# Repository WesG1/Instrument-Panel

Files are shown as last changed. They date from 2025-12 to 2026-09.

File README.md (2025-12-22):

# Instrument Panel
65 Mustang Modern Insturment Panel

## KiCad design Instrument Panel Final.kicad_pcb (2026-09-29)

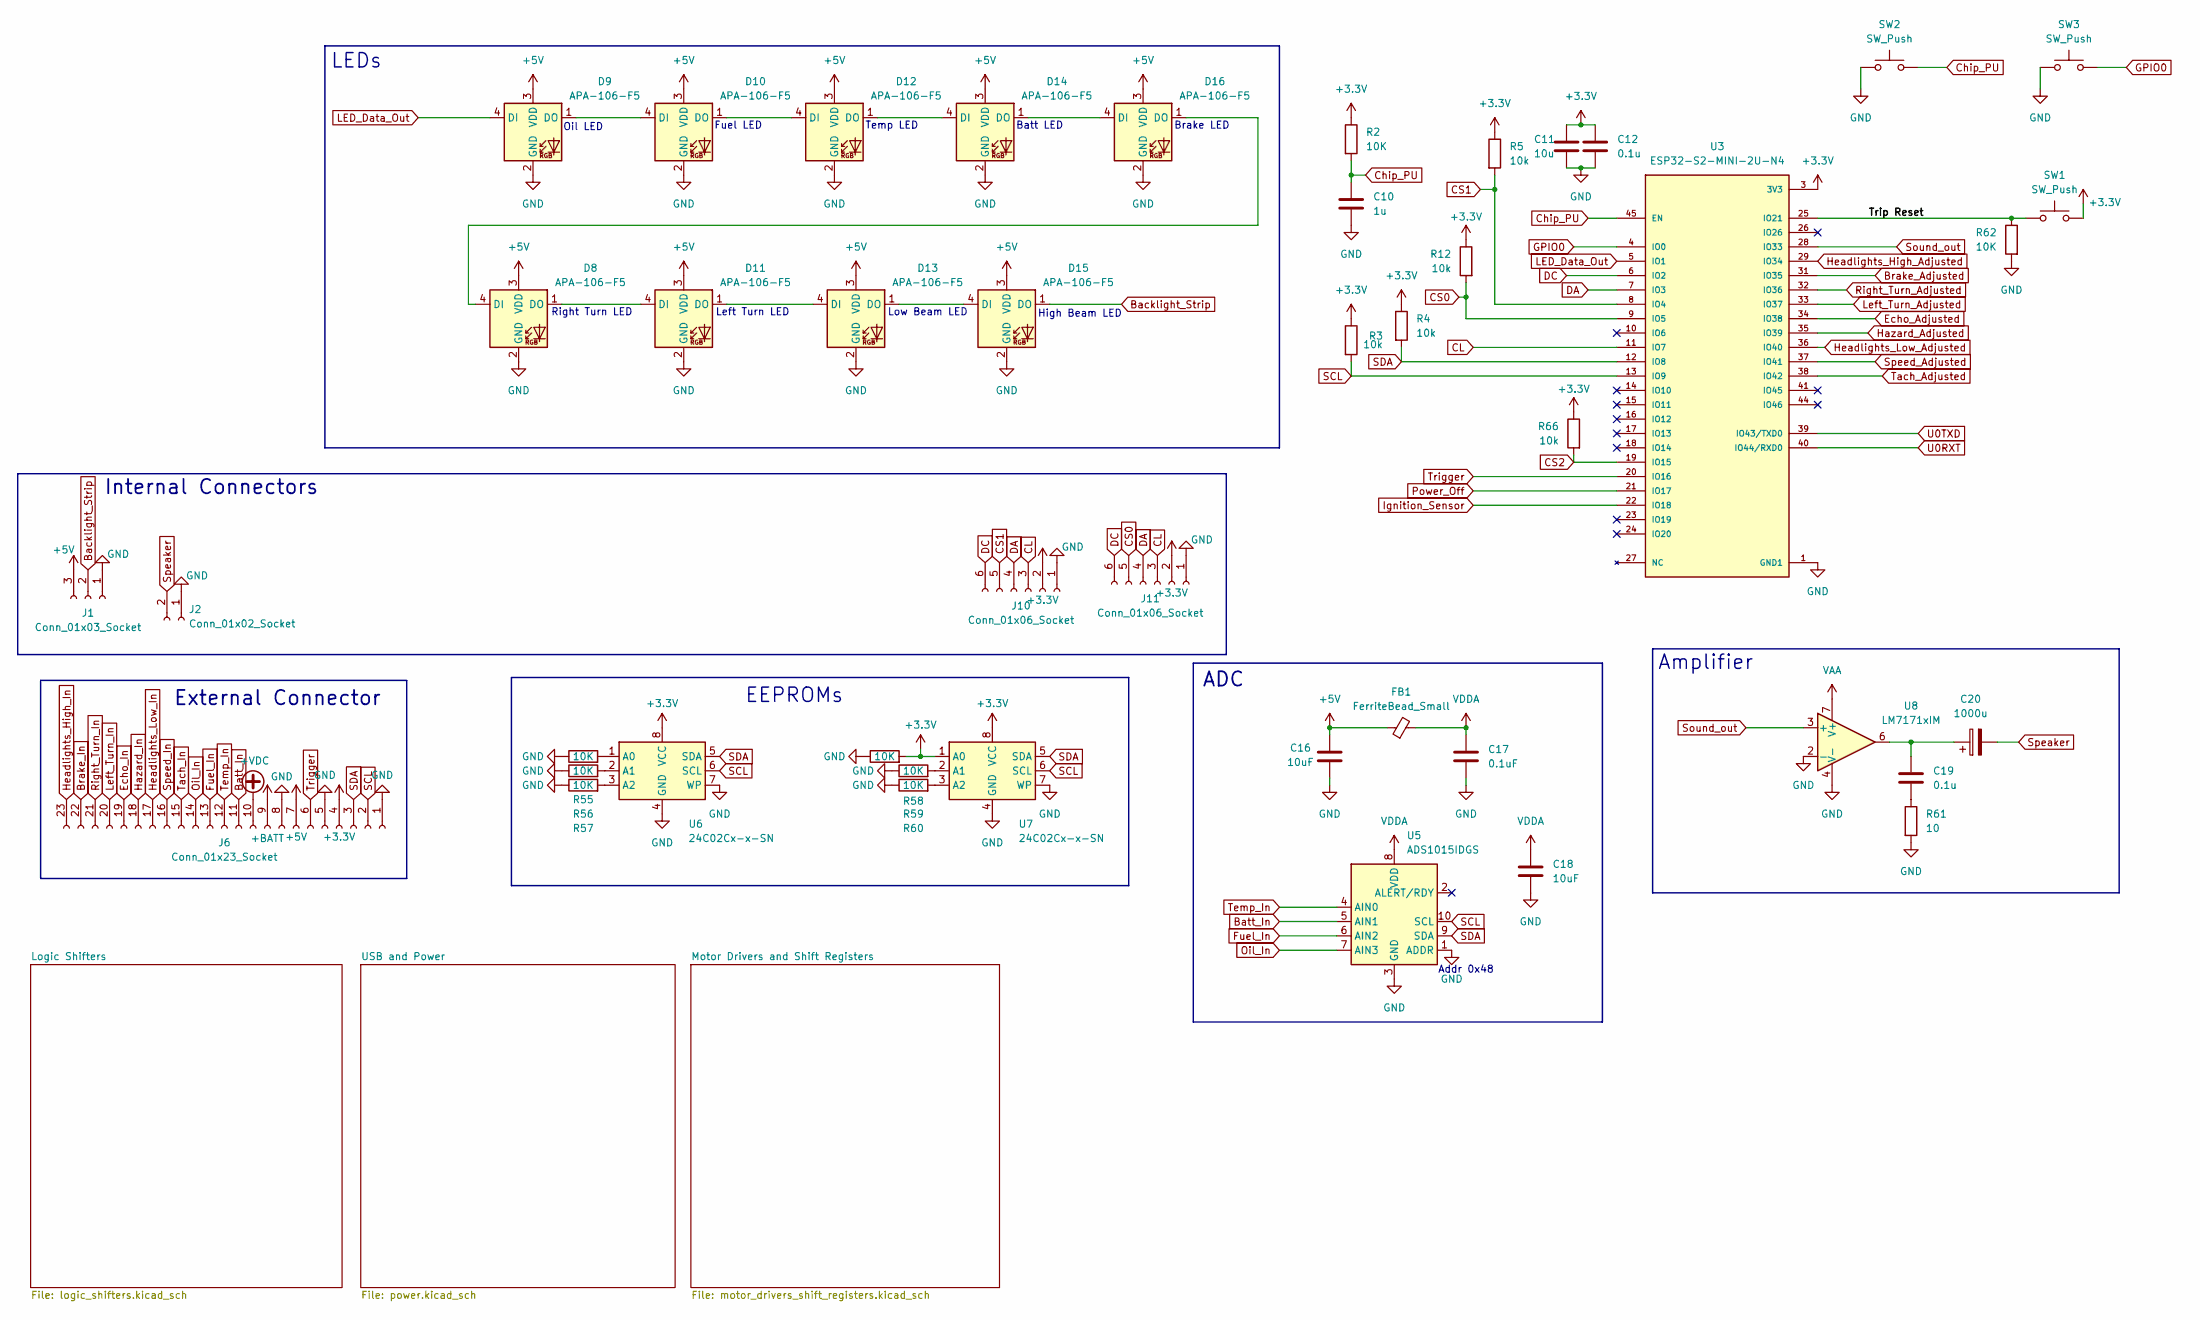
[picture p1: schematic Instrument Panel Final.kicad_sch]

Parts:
C10: 1u; C_Disc_D3.0mm_W1.6mm_P2.50mm
C11: 10u; C_Disc_D3.0mm_W1.6mm_P2.50mm
C12, C19: 0.1u; C_Disc_D3.0mm_W1.6mm_P2.50mm
C16, C18: 10uF; C_Disc_D3.0mm_W1.6mm_P2.50mm
C17: 0.1uF; C_Disc_D3.0mm_W1.6mm_P2.50mm
C20: 1000u; CP_Radial_D5.0mm_P2.50mm
D8, D9, D10, D11, D12, D13, D14, D15, D16: APA-106-F5; LED_D5.0mm-4_RGB
FB1: FerriteBead_Small; L_Axial_L5.0mm_D3.6mm_P10.00mm_Horizontal_Murata_BL01RN1A2A2
J1: Conn_01x03_Socket; Hirose_DF13-03P-1.25DSA_1x03_P1.25mm_Vertical
J2: Conn_01x02_Socket; Hirose_DF13-02P-1.25DSA_1x02_P1.25mm_Vertical
J6: Conn_01x23_Socket; Molex_SL_171971-0023_1x23_P2.54mm_Vertical
J10, J11: Conn_01x06_Socket; Hirose_DF13-06P-1.25DSA_1x06_P1.25mm_Vertical
R2, R55, R56, R57, R58, R59, R60, R62: 10K; R_Axial_DIN0207_L6.3mm_D2.5mm_P10.16mm_Horizontal
R3, R4, R5, R12, R66: 10k; R_Axial_DIN0207_L6.3mm_D2.5mm_P10.16mm_Horizontal
R61: 10; R_Axial_DIN0207_L6.3mm_D2.5mm_P10.16mm_Horizontal
SW1, SW2, SW3: SW_Push; SW_PUSH_6mm_H8mm
U3: ESP32-S2-MINI-2U-N4; XCVR_ESP32-S2-MINI-2U-N4; PARTREV v0.5
U5: ADS1015IDGS; TSSOP-10_3x3mm_P0.5mm
U6, U7: 24C02Cx-x-SN; DIP-8_W7.62mm
U8: LM7171xIM; DIP-8_W7.62mm

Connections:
+3.3V: C11.1, C12.1, J6.4, J10.2, J11.2, R2.1, R3.1, R4.1, R5.1, R12.1, R58.2, R66.1, SW1.1, U3.3 (3V3), U6.8 (VCC), U7.1 (A0), U7.8 (VCC); also elsewhere on the board
+5V: C16.1, D8.3 (VDD), D9.3 (VDD), D10.3 (VDD), D11.3 (VDD), D12.3 (VDD), D13.3 (VDD), D14.3 (VDD), D15.3 (VDD), D16.3 (VDD), FB1.1, J1.3, J6.7; also elsewhere on the board
+BATT: J6.9; also elsewhere on the board
+VDC: J6.10; also elsewhere on the board
Backlight_Strip: D15.1 (DO), J1.2
Batt_In: J6.11, U5.5 (AIN1)
Brake_Adjusted: U3.31 (IO35); also elsewhere on the board
Brake_In: J6.22; also elsewhere on the board
CL: J10.3, J11.3, U3.11 (IO7); also elsewhere on the board
CS0: J11.5, R12.2, U3.9 (IO5)
CS1: J10.5, R5.2, U3.8 (IO4)
Chip_PU: C10.1, R2.2, SW2.2, U3.45 (EN); also elsewhere on the board
DA: J10.4, J11.4, U3.7 (IO3); also elsewhere on the board
DC: J10.6, J11.6, U3.6 (IO2)
Echo_Adjusted: U3.34 (IO38); also elsewhere on the board
Echo_In: J6.19; also elsewhere on the board
Fuel_In: J6.13, U5.6 (AIN2)
GND: C10.2, C11.2, C12.2, C16.2, C17.2, C18.2, D8.2 (GND), D9.2 (GND), D10.2 (GND), D11.2 (GND), D12.2 (GND), D13.2 (GND), D14.2 (GND), D15.2 (GND), D16.2 (GND), J1.1, J2.1, J6.1, J6.5, J6.8, J10.1, J11.1, R55.1, R56.1, R57.1, R58.1, R59.1, R60.1, R61.2, R62.2, SW2.1, SW3.1, U3.1 (GND1), U3.2 (GND1__1), U3.30 (GND1__2), U3.42 (GND1__3), U3.43 (GND1__4), U3.46 (GND1__5), U3.47 (GND1__6), U3.48 (GND1__7), U3.49 (GND1__8), U3.50 (GND1__9), U3.51 (GND1__10), U3.52 (GND1__11), U3.53 (GND1__12), U3.54 (GND1__13), U3.55 (GND1__14), U3.56 (GND2), U3.57 (GND2__1), U3.58 (GND2__2), U3.59 (GND2__3), U3.60 (GND2__4), U3.61_1 (GND2__5), U3.61_2 (GND2__6), U3.61_3 (GND2__7), U3.61_4 (GND2__8), U3.61_5 (GND2__9), U3.61_6 (GND2__10), U3.61_7 (GND2__11), U3.61_8 (GND2__12), U3.61_9 (GND2__13), U3.62 (GND2__14), U3.63 (GND3), U3.64 (GND3__1), U3.65 (GND3__2), U5.1 (ADDR), U5.3 (GND), U6.4 (GND), U6.7 (WP), U7.4 (GND), U7.7 (WP), U8.2 (-), U8.4 (V-); also elsewhere on the board
GPIO0: SW3.2, U3.4 (IO0); also elsewhere on the board
Hazard_Adjusted: U3.35 (IO39); also elsewhere on the board
Hazard_In: J6.18; also elsewhere on the board
Headlights_High_Adjusted: U3.29 (IO34); also elsewhere on the board
Headlights_High_In: J6.23; also elsewhere on the board
Headlights_Low_Adjusted: U3.36 (IO40); also elsewhere on the board
Headlights_Low_In: J6.17; also elsewhere on the board
Ignition_Sensor: U3.22 (IO18); also elsewhere on the board
LED_Data_Out: D9.4 (DI), U3.5 (IO1)
Left_Turn_Adjusted: U3.33 (IO37); also elsewhere on the board
Left_Turn_In: J6.20; also elsewhere on the board
unnamed: C19.1, C20.1, U8.6
unnamed: C19.2, R61.1
unnamed: D9.1 (DO), D10.4 (DI)
unnamed: D10.1 (DO), D12.4 (DI)
unnamed: D8.1 (DO), D11.4 (DI)
unnamed: D11.1 (DO), D13.4 (DI)
unnamed: D12.1 (DO), D14.4 (DI)
unnamed: D13.1 (DO), D15.4 (DI)
unnamed: D14.1 (DO), D16.4 (DI)
unnamed: D8.4 (DI), D16.1 (DO)
unnamed: R66.2, U3.19 (IO15)
unnamed: R55.2, U6.1 (A0)
unnamed: R56.2, U6.2 (A1)
unnamed: R57.2, U6.3 (A2)
unnamed: R59.2, U7.2 (A1)
unnamed: R60.2, U7.3 (A2)
Oil_In: J6.14, U5.7 (AIN3)
Power_Off: U3.21 (IO17); also elsewhere on the board
Right_Turn_Adjusted: U3.32 (IO36); also elsewhere on the board
Right_Turn_In: J6.21; also elsewhere on the board
SCL: J6.2, R3.2, U3.13 (IO9), U5.10 (SCL), U6.6 (SCL), U7.6 (SCL)
SDA: J6.3, R4.2, U3.12 (IO8), U5.9 (SDA), U6.5 (SDA), U7.5 (SDA)
Sound_out: U3.28 (IO33), U8.3 (+)
Speaker: C20.2, J2.2
Speed_Adjusted: U3.37 (IO41); also elsewhere on the board
Speed_In: J6.16; also elsewhere on the board
Tach_Adjusted: U3.38 (IO42); also elsewhere on the board
Tach_In: J6.15; also elsewhere on the board
Temp_In: J6.12, U5.4 (AIN0)
Trigger: J6.6, U3.20 (IO16)
Trip_Reset: R62.1, SW1.2, U3.25 (IO21)
U0RXT: U3.40 (IO44/RXD0); also elsewhere on the board
U0TXD: U3.39 (IO43/TXD0); also elsewhere on the board
VAA: U8.7 (V+); also elsewhere on the board
VDDA: C17.1, C18.1, FB1.2, U5.8 (VDD)

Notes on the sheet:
Brake LED
Batt LED
High Beam LED
Addr 0x48
LEDs
Fuel LED
Left Turn LED
ADC
Amplifier
Temp LED
EEPROMs
Oil LED
Low Beam LED
Right Turn LED
External Connector
Internal Connectors

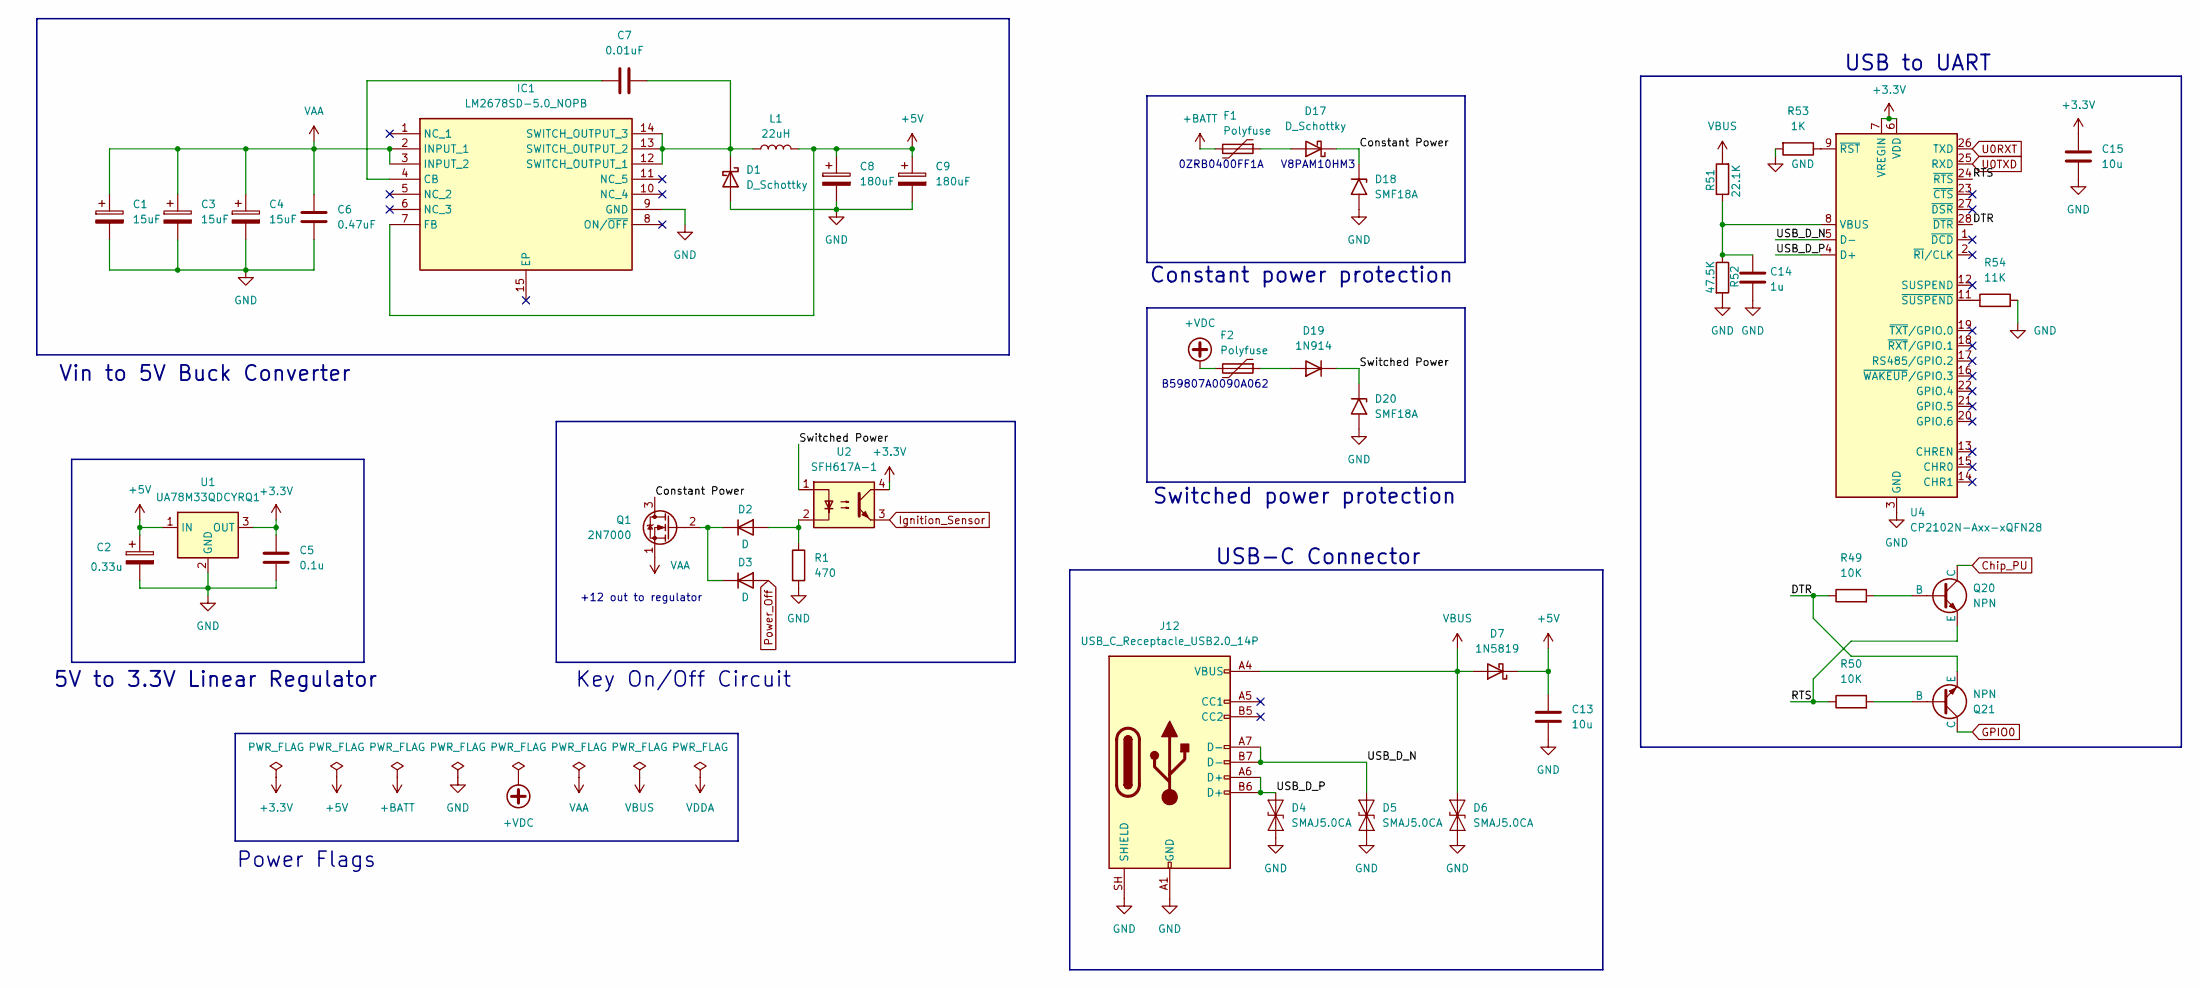
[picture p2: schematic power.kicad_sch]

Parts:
C1, C3, C4: 15uF; CP_Radial_D5.0mm_P2.50mm
C2: 0.33u; CP_Radial_D5.0mm_P2.50mm
C5: 0.1u; C_Disc_D3.0mm_W1.6mm_P2.50mm
C6: 0.47uF; C_Disc_D3.0mm_W1.6mm_P2.50mm
C7: 0.01uF; C_Disc_D3.0mm_W1.6mm_P2.50mm
C8, C9: 180uF; CP_Radial_D5.0mm_P2.50mm
C13, C15: 10u; C_Disc_D3.0mm_W1.6mm_P2.50mm
C14: 1u; C_Disc_D3.0mm_W1.6mm_P2.50mm
D1: D_Schottky; D_A-405_P7.62mm_Horizontal
D2, D3: D; D_A-405_P7.62mm_Horizontal
D4, D5, D6: SMAJ5.0CA; D_SMA
D7: 1N5819; D_DO-41_SOD81_P10.16mm_Horizontal
D17: D_Schottky; Vishay_SMPA
D18, D20: SMF18A; D_SMF
D19: 1N914; D_DO-35_SOD27_P7.62mm_Horizontal
F1: Polyfuse; Fuse_BelFuse_0ZRE0005FF_L8.3mm_W3.8mm
F2: Polyfuse; Fuse_1210_3225Metric
IC1: LM2678SD-5.0_NOPB; VSON-14-1EP_3x4.45mm_P0.65mm_EP1.6x4.2mm; Manufacturer_Part_Number LM2678SD-5.0/NOPB; Mouser Part Number 926-LM2678SD50NOPB
J12: USB_C_Receptacle_USB2.0_14P; USB_C_Receptacle_GCT_USB4085
L1: 22uH; L_Radial_D9.5mm_P5.00mm_Fastron_07HVP
Q1: 2N7000; TO-92_Inline
Q20, Q21: NPN; TO-92_Inline
R1: 470; R_Axial_DIN0207_L6.3mm_D2.5mm_P10.16mm_Horizontal
R49, R50: 10K; R_Axial_DIN0207_L6.3mm_D2.5mm_P10.16mm_Horizontal
R51: 22.1K; R_Axial_DIN0207_L6.3mm_D2.5mm_P10.16mm_Horizontal
R52: 47.5K; R_Axial_DIN0207_L6.3mm_D2.5mm_P10.16mm_Horizontal
R53: 1K; R_Axial_DIN0207_L6.3mm_D2.5mm_P10.16mm_Horizontal
R54: 11K; R_Axial_DIN0207_L6.3mm_D2.5mm_P10.16mm_Horizontal
U1: UA78M33QDCYRQ1; SOT-223-3_TabPin2
U2: SFH617A-1; DIP-4_W7.62mm
U4: CP2102N-Axx-xQFN28; QFN-28-1EP_5x5mm_P0.5mm_EP3.35x3.35mm

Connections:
+3.3V: C5.1, C15.1, U1.3 (OUT), U2.4, U4.6 (VDD), U4.7 (VREGIN); also elsewhere on the board
+5V: C2.1, C8.1, C9.1, C13.1, D7.1 (K), IC1.7 (FB), L1.2, U1.1 (IN); also elsewhere on the board
+BATT: F1.2; also elsewhere on the board
+VDC: F2.2; also elsewhere on the board
/Power/Constant Power: D17.1 (K), D18.1 (A1), Q1.3 (D)
/Power/Switched Power: D19.1 (K), D20.1 (A1), U2.1
/USB/DTR: Q21.3 (E), R49.1, U4.28 (~DTR)
/USB/RTS: Q20.3 (E), R50.1, U4.24 (~RTS)
/USB/USB_D_N: D5.2 (A2), J12.A7 (D-), J12.B7 (D-), U4.5 (D-)
/USB/USB_D_P: D4.2 (A2), J12.A6 (D+), J12.B6 (D+), U4.4 (D+)
Chip_PU: Q20.1 (C); also elsewhere on the board
GND: C1.2, C2.2, C3.2, C4.2, C5.2, C6.2, C8.2, C9.2, C13.2, C14.2, C15.2, D1.2 (A), D4.1 (A1), D5.1 (A1), D6.1 (A1), D18.2 (A2), D20.2 (A2), IC1.9 (GND), J12.A1 (GND), J12.A12 (GND), J12.B1 (GND), J12.B12 (GND), J12.SH (SHIELD), R1.2, R52.2, R53.2, R54.2, U1.2 (GND), U4.3 (GND), U4.29 (GND); also elsewhere on the board
GPIO0: Q21.1 (C); also elsewhere on the board
Ignition_Sensor: U2.3; also elsewhere on the board
unnamed: C7.2, D1.1 (K), IC1.12 (SWITCH_OUTPUT_1), IC1.13 (SWITCH_OUTPUT_2), IC1.14 (SWITCH_OUTPUT_3), L1.1
unnamed: D2.2 (A), R1.1, U2.2
unnamed: D2.1 (K), D3.1 (K), Q1.2 (G)
unnamed: D17.2 (A), F1.1
unnamed: D19.2 (A), F2.1
unnamed: C7.1, IC1.4 (CB)
unnamed: Q20.2 (B), R49.2
unnamed: Q21.2 (B), R50.2
unnamed: C14.1, R51.1, R52.1, U4.8 (VBUS)
unnamed: R53.1, U4.9 (~RST)
unnamed: R54.1, U4.11 (~SUSPEND)
Power_Off: D3.2 (A); also elsewhere on the board
U0RXT: U4.26 (TXD); also elsewhere on the board
U0TXD: U4.25 (RXD); also elsewhere on the board
VAA: C1.1, C3.1, C4.1, C6.1, IC1.2 (INPUT_1), IC1.3 (INPUT_2), Q1.1 (S); also elsewhere on the board
VBUS: D6.2 (A2), D7.2 (A), J12.A4 (VBUS), J12.A9 (VBUS), J12.B4 (VBUS), J12.B9 (VBUS), R51.2

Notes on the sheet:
USB to UART
V8PAM10HM3
0ZRB0400FF1A
Constant power protection
Key On/Off Circuit
+12 out to regulator
Vin to 5V Buck Converter
B59807A0090A062
Power Flags
USB-C Connector
5V to 3.3V Linear Regulator
Switched power protection

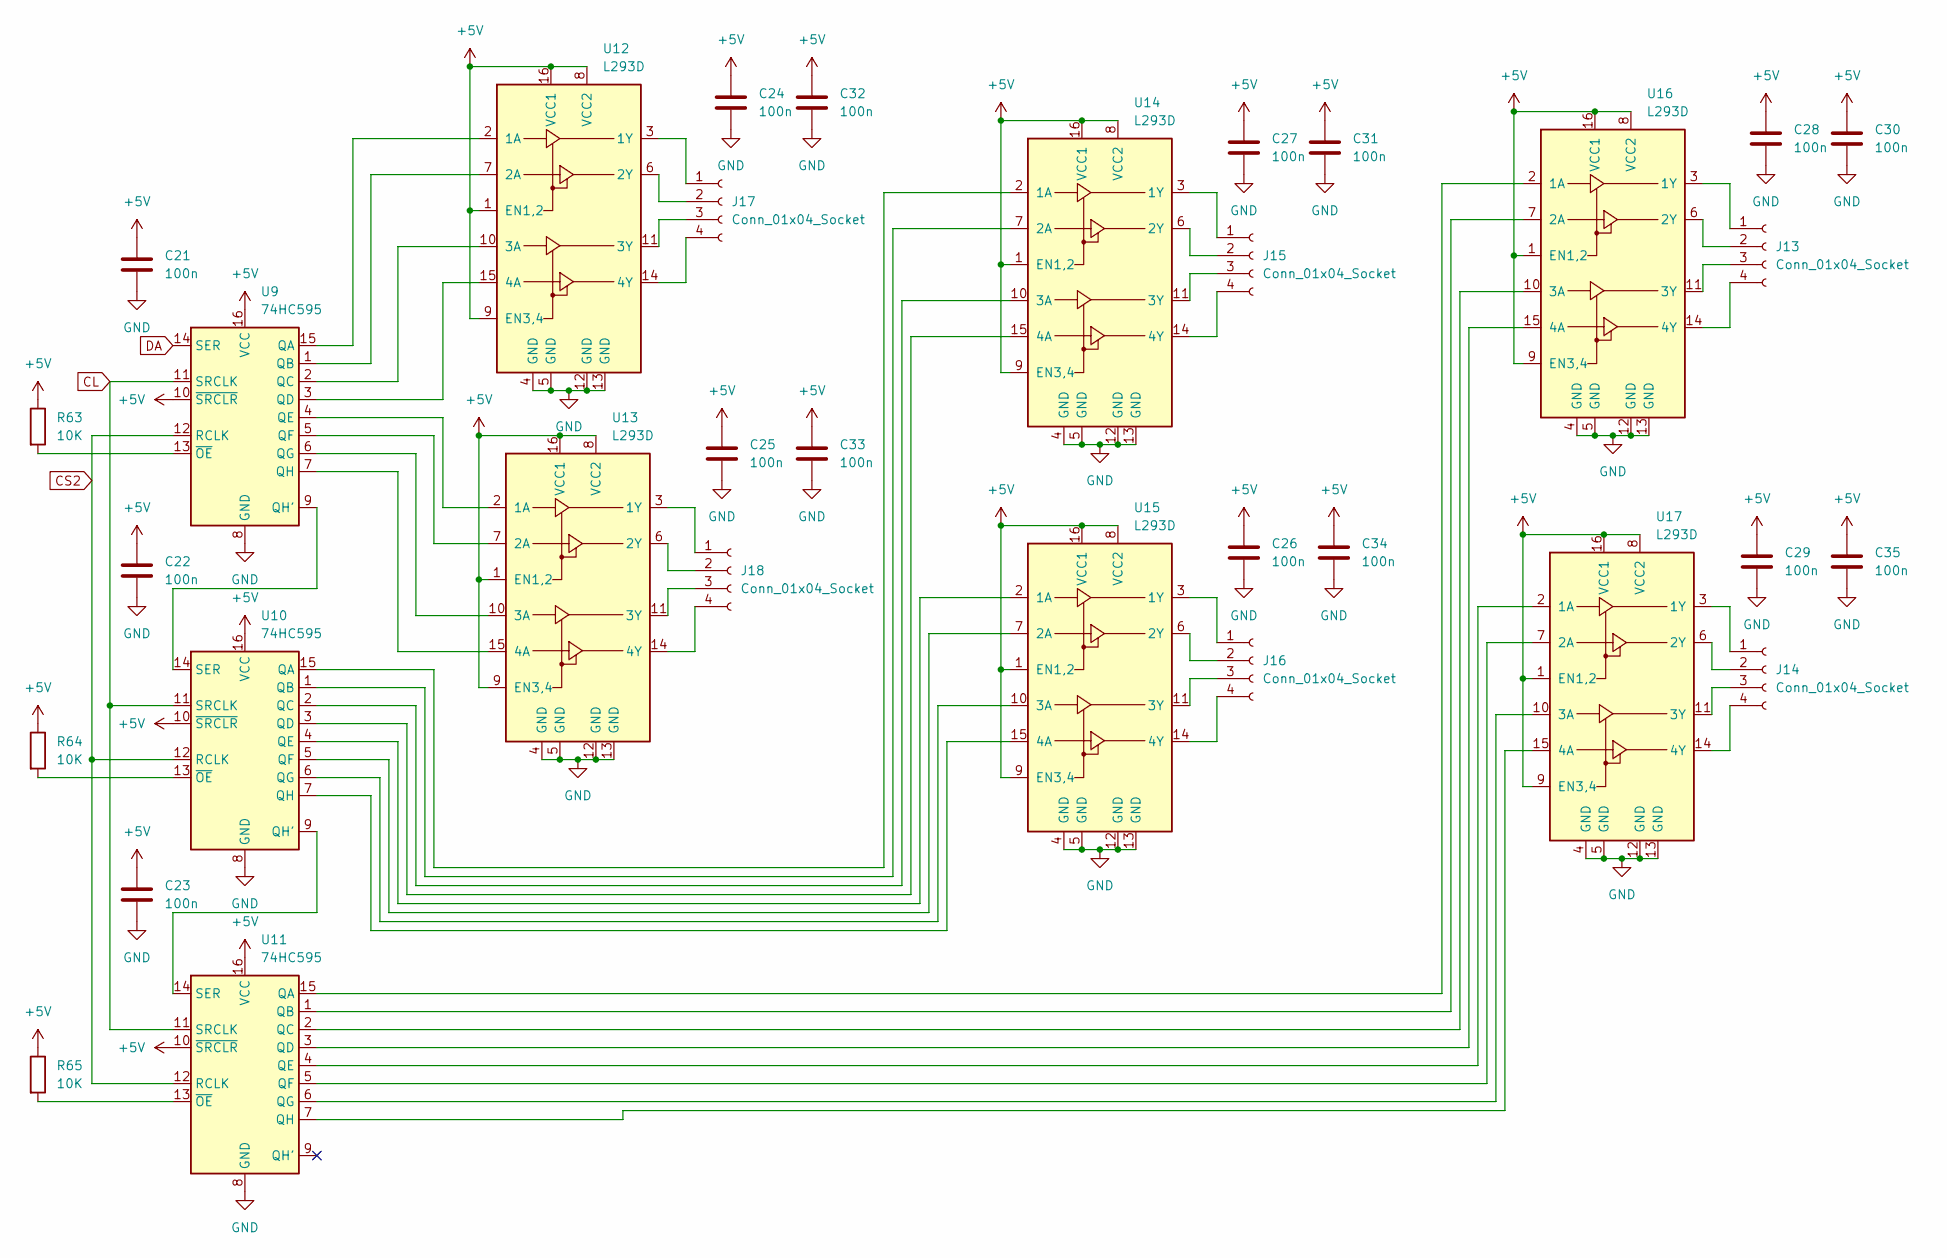
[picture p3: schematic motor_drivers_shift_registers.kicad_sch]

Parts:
C21, C22, C23, C24, C25, C26, C27, C28, C29, C30, C31, C32, C33, C34, C35: 100n; C_Disc_D3.0mm_W1.6mm_P2.50mm
J13, J14, J15, J16, J17, J18: Conn_01x04_Socket; Hirose_DF13-04P-1.25DSA_1x04_P1.25mm_Vertical
R63, R64, R65: 10K; R_Axial_DIN0207_L6.3mm_D2.5mm_P10.16mm_Horizontal
U9, U10, U11: 74HC595; DIP-16_W7.62mm
U12, U13, U14, U15, U16, U17: L293D; DIP-16_W7.62mm

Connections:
+5V: C21.1, C22.1, C23.1, C24.1, C25.1, C26.1, C27.1, C28.1, C29.1, C30.1, C31.1, C32.1, C33.1, C34.1, C35.1, R63.1, R64.1, R65.1, U9.10 (~SRCLR), U9.16 (VCC), U10.10 (~SRCLR), U10.16 (VCC), U11.10 (~SRCLR), U11.16 (VCC), U12.1 (EN1,2), U12.8 (VCC2), U12.9 (EN3,4), U12.16 (VCC1), U13.1 (EN1,2), U13.8 (VCC2), U13.9 (EN3,4), U13.16 (VCC1), U14.1 (EN1,2), U14.8 (VCC2), U14.9 (EN3,4), U14.16 (VCC1), U15.1 (EN1,2), U15.8 (VCC2), U15.9 (EN3,4), U15.16 (VCC1), U16.1 (EN1,2), U16.8 (VCC2), U16.9 (EN3,4), U16.16 (VCC1), U17.1 (EN1,2), U17.8 (VCC2), U17.9 (EN3,4), U17.16 (VCC1); also elsewhere on the board
CL: U9.11 (SRCLK), U10.11 (SRCLK), U11.11 (SRCLK); also elsewhere on the board
CS2: U9.12 (RCLK), U10.12 (RCLK), U11.12 (RCLK)
DA: U9.14 (SER); also elsewhere on the board
GND: C21.2, C22.2, C23.2, C24.2, C25.2, C26.2, C27.2, C28.2, C29.2, C30.2, C31.2, C32.2, C33.2, C34.2, C35.2, U9.8 (GND), U10.8 (GND), U11.8 (GND), U12.4 (GND), U12.5 (GND), U12.12 (GND), U12.13 (GND), U13.4 (GND), U13.5 (GND), U13.12 (GND), U13.13 (GND), U14.4 (GND), U14.5 (GND), U14.12 (GND), U14.13 (GND), U15.4 (GND), U15.5 (GND), U15.12 (GND), U15.13 (GND), U16.4 (GND), U16.5 (GND), U16.12 (GND), U16.13 (GND), U17.4 (GND), U17.5 (GND), U17.12 (GND), U17.13 (GND); also elsewhere on the board
unnamed: J13.1, U16.3 (1Y)
unnamed: J13.2, U16.6 (2Y)
unnamed: J13.3, U16.11 (3Y)
unnamed: J13.4, U16.14 (4Y)
unnamed: J14.1, U17.3 (1Y)
unnamed: J14.2, U17.6 (2Y)
unnamed: J14.3, U17.11 (3Y)
unnamed: J14.4, U17.14 (4Y)
unnamed: J15.1, U14.3 (1Y)
unnamed: J15.2, U14.6 (2Y)
unnamed: J15.3, U14.11 (3Y)
unnamed: J15.4, U14.14 (4Y)
unnamed: J16.1, U15.3 (1Y)
unnamed: J16.2, U15.6 (2Y)
unnamed: J16.3, U15.11 (3Y)
unnamed: J16.4, U15.14 (4Y)
unnamed: J17.1, U12.3 (1Y)
unnamed: J17.2, U12.6 (2Y)
unnamed: J17.3, U12.11 (3Y)
unnamed: J17.4, U12.14 (4Y)
unnamed: J18.1, U13.3 (1Y)
unnamed: J18.2, U13.6 (2Y)
unnamed: J18.3, U13.11 (3Y)
unnamed: J18.4, U13.14 (4Y)
unnamed: R63.2, U9.13 (~OE)
unnamed: U10.15 (QA), U14.2 (1A)
unnamed: U10.1 (QB), U14.7 (2A)
unnamed: U10.2 (QC), U14.10 (3A)
unnamed: U10.3 (QD), U14.15 (4A)
unnamed: U10.4 (QE), U15.2 (1A)
unnamed: U10.5 (QF), U15.7 (2A)
unnamed: U10.6 (QG), U15.10 (3A)
unnamed: U10.9 (QH'), U11.14 (SER)
unnamed: U10.7 (QH), U15.15 (4A)
unnamed: U9.9 (QH'), U10.14 (SER)
unnamed: R64.2, U10.13 (~OE)
unnamed: U11.15 (QA), U16.2 (1A)
unnamed: U11.1 (QB), U16.7 (2A)
unnamed: U11.2 (QC), U16.10 (3A)
unnamed: U11.3 (QD), U16.15 (4A)
unnamed: U11.4 (QE), U17.2 (1A)
unnamed: U11.5 (QF), U17.7 (2A)
unnamed: U11.6 (QG), U17.10 (3A)
unnamed: U11.7 (QH), U17.15 (4A)
unnamed: R65.2, U11.13 (~OE)
unnamed: U9.15 (QA), U12.2 (1A)
unnamed: U9.1 (QB), U12.7 (2A)
unnamed: U9.2 (QC), U12.10 (3A)
unnamed: U9.3 (QD), U12.15 (4A)
unnamed: U9.4 (QE), U13.2 (1A)
unnamed: U9.5 (QF), U13.7 (2A)
unnamed: U9.6 (QG), U13.10 (3A)
unnamed: U9.7 (QH), U13.15 (4A)

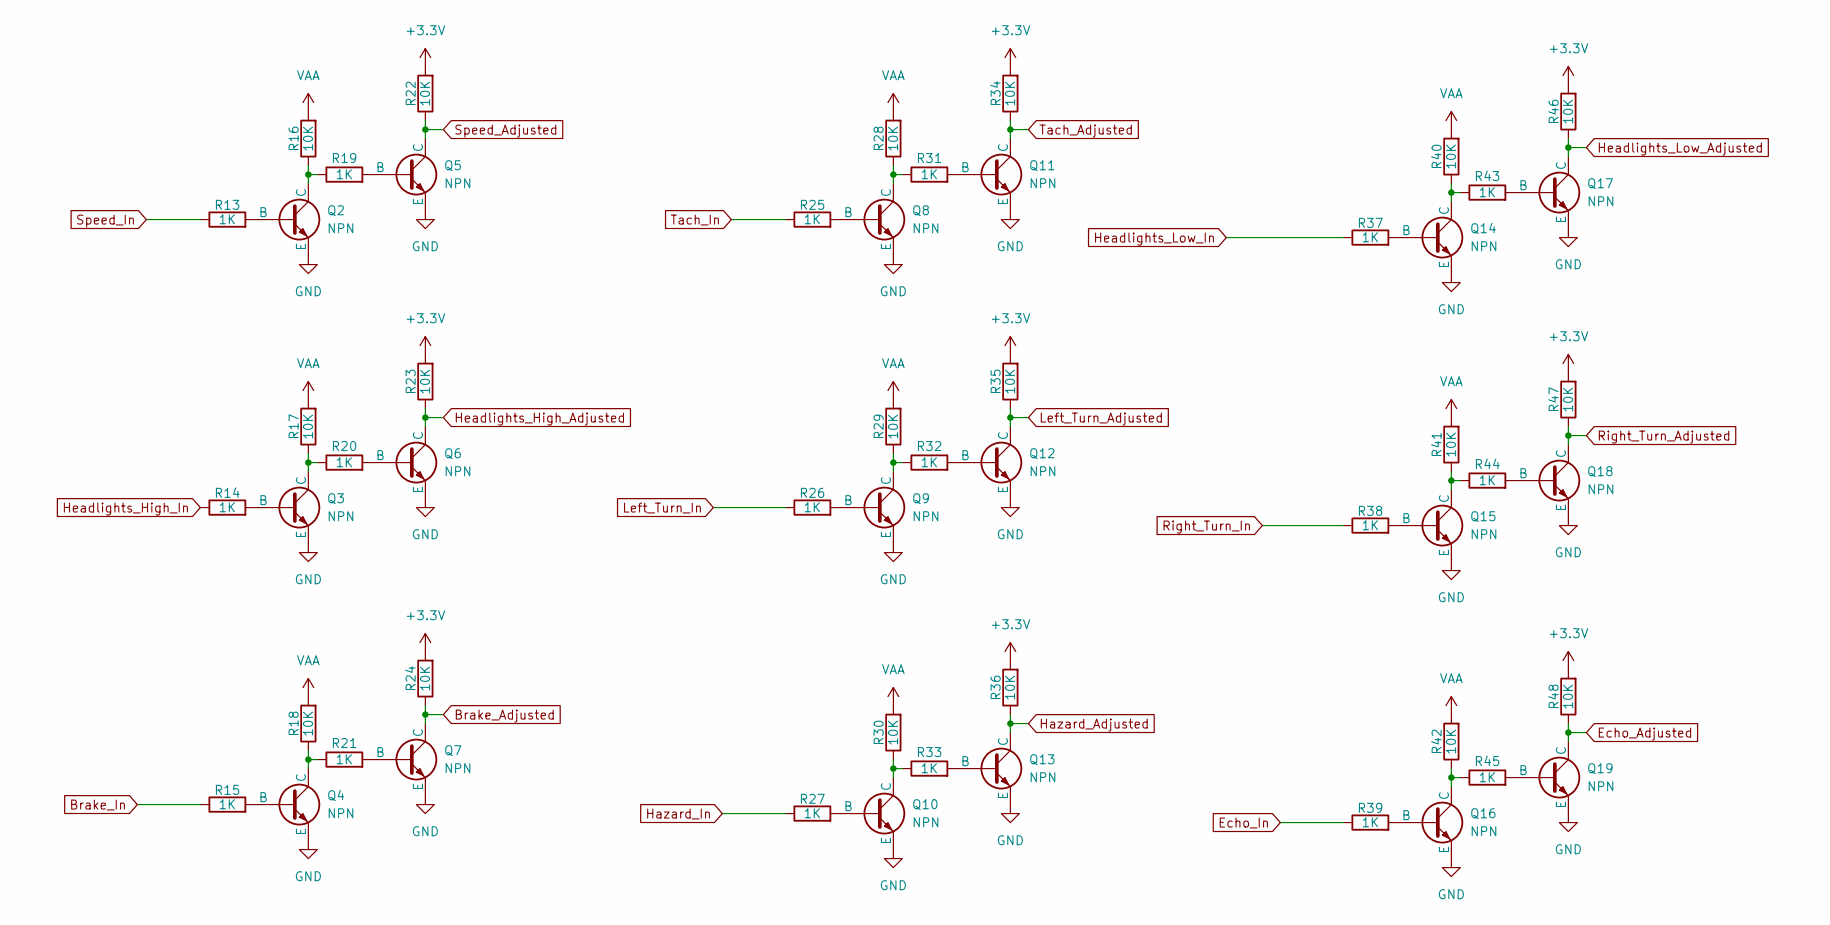
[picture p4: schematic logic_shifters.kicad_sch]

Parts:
Q2, Q3, Q4, Q5, Q6, Q7, Q8, Q9, Q10, Q11, Q12, Q13, Q14, Q15, Q16, Q17, Q18, Q19: NPN; TO-92_Inline
R13, R14, R15, R19, R20, R21, R25, R26, R27, R31, R32, R33, R37, R38, R39, R43, R44, R45: 1K; R_Axial_DIN0207_L6.3mm_D2.5mm_P10.16mm_Horizontal
R16, R17, R18, R22, R23, R24, R28, R29, R30, R34, R35, R36, R40, R41, R42, R46, R47, R48: 10K; R_Axial_DIN0207_L6.3mm_D2.5mm_P10.16mm_Horizontal

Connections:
+3.3V: R22.2, R23.2, R24.2, R34.2, R35.2, R36.2, R46.2, R47.2, R48.2; also elsewhere on the board
Brake_Adjusted: Q7.1 (C), R24.1; also elsewhere on the board
Brake_In: R15.1; also elsewhere on the board
Echo_Adjusted: Q19.1 (C), R48.1; also elsewhere on the board
Echo_In: R39.1; also elsewhere on the board
GND: Q2.3 (E), Q3.3 (E), Q4.3 (E), Q5.3 (E), Q6.3 (E), Q7.3 (E), Q8.3 (E), Q9.3 (E), Q10.3 (E), Q11.3 (E), Q12.3 (E), Q13.3 (E), Q14.3 (E), Q15.3 (E), Q16.3 (E), Q17.3 (E), Q18.3 (E), Q19.3 (E); also elsewhere on the board
Hazard_Adjusted: Q13.1 (C), R36.1; also elsewhere on the board
Hazard_In: R27.1; also elsewhere on the board
Headlights_High_Adjusted: Q6.1 (C), R23.1; also elsewhere on the board
Headlights_High_In: R14.1; also elsewhere on the board
Headlights_Low_Adjusted: Q17.1 (C), R46.1; also elsewhere on the board
Headlights_Low_In: R37.1; also elsewhere on the board
Left_Turn_Adjusted: Q12.1 (C), R35.1; also elsewhere on the board
Left_Turn_In: R26.1; also elsewhere on the board
unnamed: Q2.2 (B), R13.2
unnamed: Q2.1 (C), R16.1, R19.1
unnamed: Q3.2 (B), R14.2
unnamed: Q3.1 (C), R17.1, R20.1
unnamed: Q4.2 (B), R15.2
unnamed: Q4.1 (C), R18.1, R21.1
unnamed: Q5.2 (B), R19.2
unnamed: Q6.2 (B), R20.2
unnamed: Q7.2 (B), R21.2
unnamed: Q8.2 (B), R25.2
unnamed: Q8.1 (C), R28.1, R31.1
unnamed: Q9.2 (B), R26.2
unnamed: Q9.1 (C), R29.1, R32.1
unnamed: Q10.2 (B), R27.2
unnamed: Q10.1 (C), R30.1, R33.1
unnamed: Q11.2 (B), R31.2
unnamed: Q12.2 (B), R32.2
unnamed: Q13.2 (B), R33.2
unnamed: Q14.2 (B), R37.2
unnamed: Q14.1 (C), R40.1, R43.1
unnamed: Q15.2 (B), R38.2
unnamed: Q15.1 (C), R41.1, R44.1
unnamed: Q16.2 (B), R39.2
unnamed: Q16.1 (C), R42.1, R45.1
unnamed: Q17.2 (B), R43.2
unnamed: Q18.2 (B), R44.2
unnamed: Q19.2 (B), R45.2
Right_Turn_Adjusted: Q18.1 (C), R47.1; also elsewhere on the board
Right_Turn_In: R38.1; also elsewhere on the board
Speed_Adjusted: Q5.1 (C), R22.1; also elsewhere on the board
Speed_In: R13.1; also elsewhere on the board
Tach_Adjusted: Q11.1 (C), R34.1; also elsewhere on the board
Tach_In: R25.1; also elsewhere on the board
VAA: R16.2, R17.2, R18.2, R28.2, R29.2, R30.2, R40.2, R41.2, R42.2; also elsewhere on the board

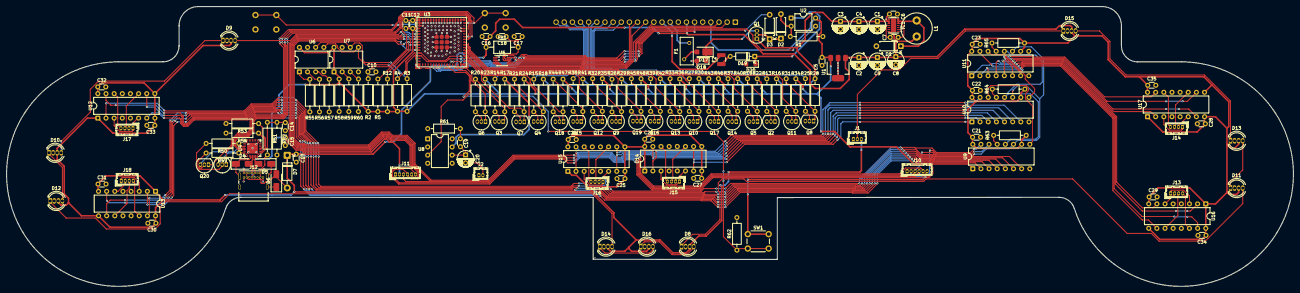
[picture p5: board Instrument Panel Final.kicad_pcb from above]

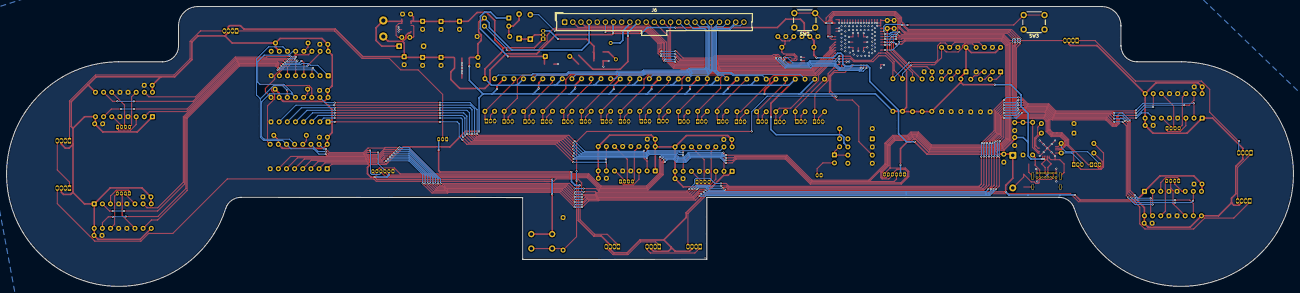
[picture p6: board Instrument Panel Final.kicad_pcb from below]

Board: 2 copper layers, 401.2 x 87.2 mm, 172 parts (3 on the bottom side), 162 nets.
